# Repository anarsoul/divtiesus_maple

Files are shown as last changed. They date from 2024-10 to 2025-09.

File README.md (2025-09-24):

# [DivTIESUS Maple Edition](https://anarsoul.github.io/divtiesus_maple)
DivTIESUS Maple Edition is a SD/MMC card interface for the ZX Spectrum. It is based on Miguel's [DivTIESUS](https://github.com/mcleod-ideafix/divtiesus), but adds joystick port and serial port for WiFi at the expense of Soft +3E feature. I redid whole project in KiCAD and rerouted the PCB. CPLD pin assignment has been changed to accommodate new PCB layout.

You can [buy me a coffee](https://ko-fi.com/anarsoul) if you want to say thank you.

# Features
- DivMMC compatible interface with 8 KiB of EEPROM and 128 KiB or 512 KiB of RAM. Standard utils for EEPROM flashing, as provided by the ESXDOS team, are compatible with DivTIESUS.
- Model autodetection. This means you don't need to put a jumper, or flip a switch to change from using it with a Spectrum 48K and a +3.
- Tested with original Spectrum+, Black +2, Harlequin 128 rev. 2D and rev. 4B, Karabas 128 rev. B1. More testing reports will be appreciated
- It uses its own fast clock (24 MHz). It does not need the CPU clock at all.
- NMI button to call file browser in ESXDOS, and handy RESET button.
- MicroSD card slot
- DIP switches for enabling EEPROM flashing and disabling auto-mapping (bottom switch) and for disabling built-in joystick interface (top switch)
- Optional: Zx-Uno-compatible UART (running at 115200 baud) with WiFi. Do not place ESP12 if you are not planning to use it
- Optional: Built-in Kempston joystick interface, compatible with either Atari-style joystick or Sega Genesis joystick (3 or 6-button). Do not place DB9 connector and U6 (74HC165) if you are not planning to use it and disable it with a DIP switch. All 3 buttons are implemented (so called "extended Kempston")
- Joystick interface maps "A" button as "UP" if "Start" button is pressed during machine reset.
- Visual feedback for SD activity (blue led)
- ESXDOS shadowing does not collide with all-RAM feature in +2A/B/3 machines. If the system is in all-RAM mode, ESXDOS ROM mapping is disabled.
- Included STLs for 3D printing an enclosure

# Pictures
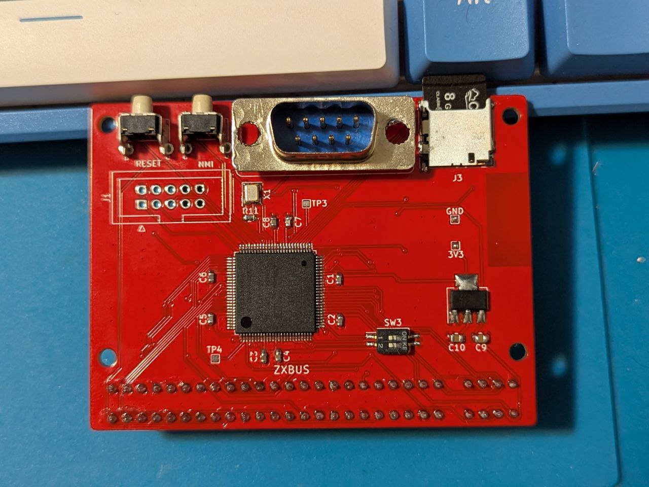
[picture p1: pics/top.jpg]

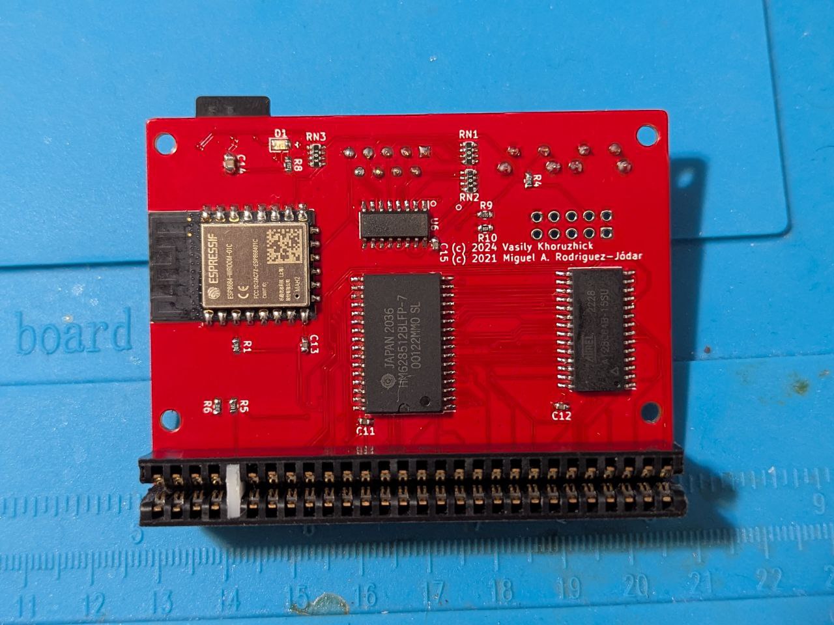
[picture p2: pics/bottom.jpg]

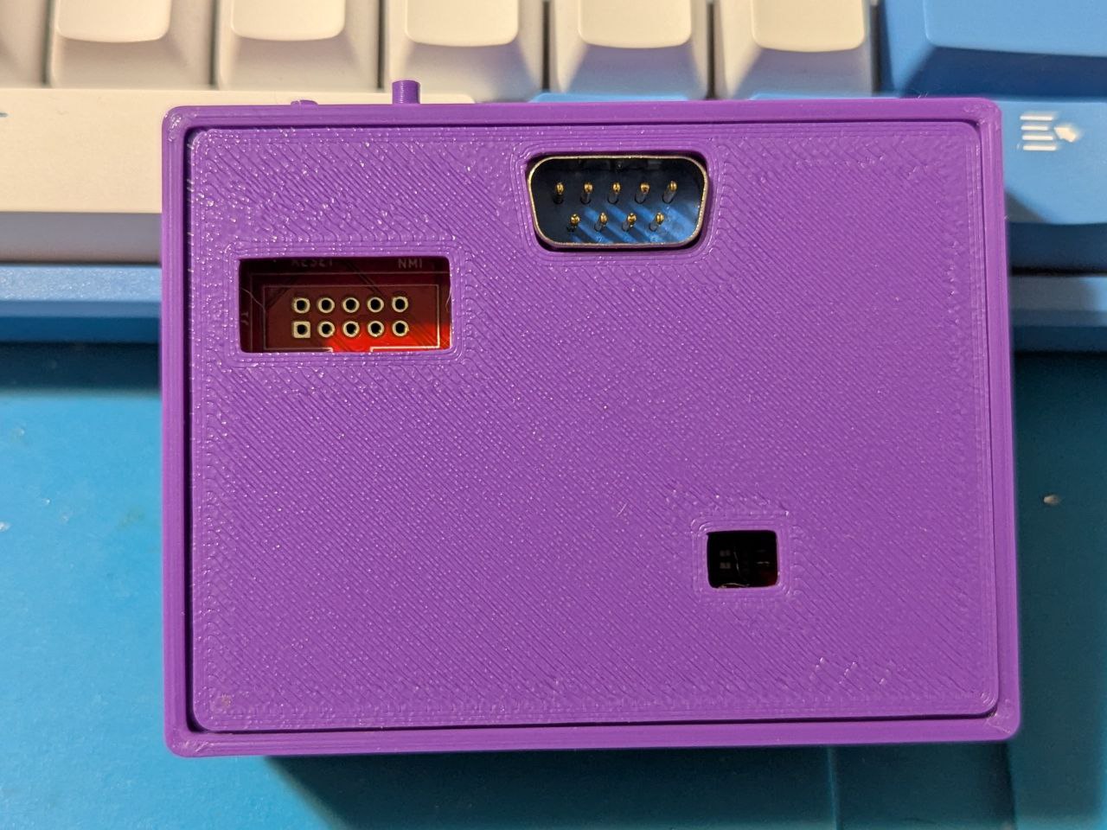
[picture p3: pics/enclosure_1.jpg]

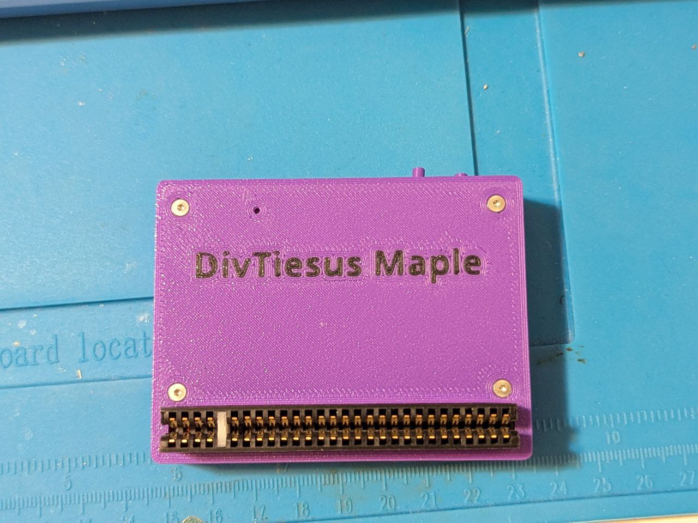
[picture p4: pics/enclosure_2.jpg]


# Schematic

Schematics can be found [here](out/schematics.pdf)

# Build
- First, you need the DivTIESUS Maple Edition PCB. You can order it from JLCPCB or from PCBWay using `divtiesus_maple_rev2.zip` file from out directory. There is also a [project on PCBWay](https://www.pcbway.com/project/shareproject/DivTIESUS_Maple_Edition_rev_2_c9d0d700.html) if you want to support me
- Second, source the components. Most of the components are rather standard so you can buy it off DigiKey or Mouser. All of them can also be obtained from AliExpress. Be careful with components from Aliexpress, especially if the price is too good to be true

## Bill of materials

Interactive BOM can be found [here](out/bom/ibom.html)

Links to some components:

|Qty|Component|Link|
|---|---|---|
|1|EPM240T100|[link](https://www.aliexpress.com/item/1005003990429762.html)|
|1|DIP switches, 2 position|[link](https://www.aliexpress.com/item/33027764033.html)|
|1|RAM|[link](https://www.aliexpress.com/item/1005002495799688.html)|
|1|EEPROM|[link](https://www.aliexpress.com/item/1005003773070206.html)|
|1|ZX Bus connector, 56pin|[link](https://www.aliexpress.com/item/1005002212044956.html)|
|2|Buttons, 6x6x6H|[link](https://www.aliexpress.com/item/1005005129319965.html)|
|1|microSD slot|[link](https://www.aliexpress.com/item/1005006255074403.html)|
|1|Crystal oscillator, 24Mhz|[link](https://www.aliexpress.com/item/1005005879624979.html)|

- The oscillator does not need to be 24 MHz, but if you use a different value, you'll have to resynthesize CPLD image, otherwise WiFi will not work
- I usually start with placing the CPLD first and programming it. Note: you'll need to supply 3.3V in order to program CPLD, there are GND and 3.3V test points left for this purpose. I source CPLDs from Aliexpress and some of them are coming dead. It is easier to test and replace it before the rest of the components are populated.
- Then place the passives (resistors, resistor arrays, capacitors) and the LED
- Then RAM, EEPROM, microSD socket, DB9 connector and ESP12. You can either leave EEPROM blank or preprogram it. Either way is fine, it can be programmed in-system later, but having EEPROM with known contents may simplify troubleshooting

## First electrical testing
- Check that there is no shorts on the 5V and 3.3V power rails.
- Use a microscope or a magnifying glass to check that there is no shorts between adjacent pads at the CPLD chip.

After all the checks, proceed to build and solder the ZX Spectrum bus connector:

## ZX Spectrum bus connector
- Take the 2x28 pin edge connector and cut about 1-2mm on each side to leave the ends opened, refer to original DivTIESUS README.
- Pull and extract the two metal contacts that are positioned at 5th place, where the index tab will be placed
- Now take a small piece you can get from a PCB, 1.5mm thick and 7mm tall. This will be the index tab.
- As an alternative, you can 3D-print the tab, you can find the model [here](https://www.thingiverse.com/thing:6556638)
- Place the tab in the index hole. Sand it if it's too tall for the hole.
- Using a pair of pliers, push it in place. If it's too small for the hole, use some glue to keep it from coming loose.

Now the edge connector is ready to work as a ZX Spectrum rear bus connector!

## Enclosure

Enclosure can be printed in pretty much any plastic. You need `button-2-nmi.stl`, `button-2-reset.stl`, `enclosure.stl` and `enclosure_top.stl` or `enclosure_top_no_jtag_no_switch.stl` if you don't want the holes for JTAG and the switch. Personally, I printed the parts in PLA and PETG. ABS should work as well. Keep in mind that PLA will soften at ~60C, so avoid using it for enclosure if you are planning to use the device with an original machine. Modern clones are fine, they are usually using CMOS ICs and modern voltage regulators that do not produce much heat.

First, place the buttons, short button (reset) closer to the edge

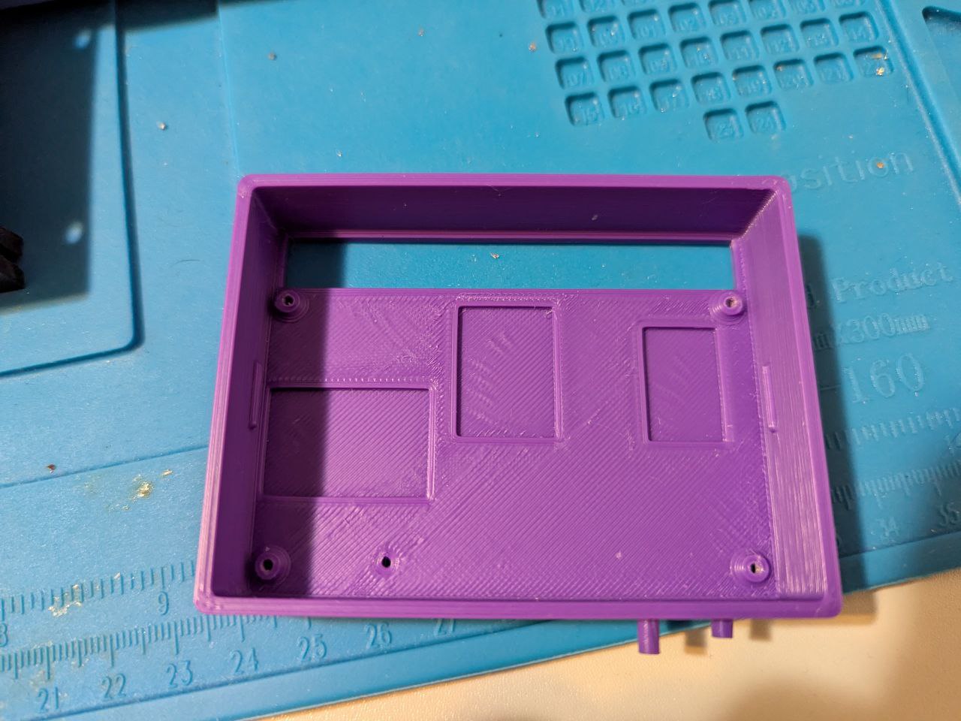
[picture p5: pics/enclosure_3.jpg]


Then insert the PCB. Be careful to keep it straight and don't let the buttons to fall out

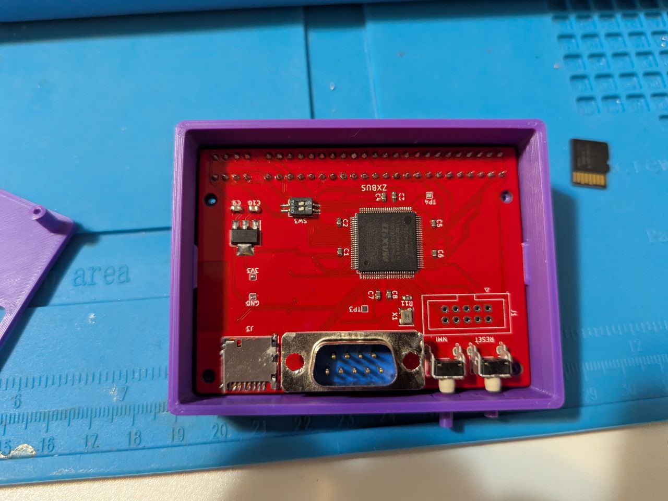
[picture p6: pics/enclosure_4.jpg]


Use 4 M2x8 screws to fix enclosure top

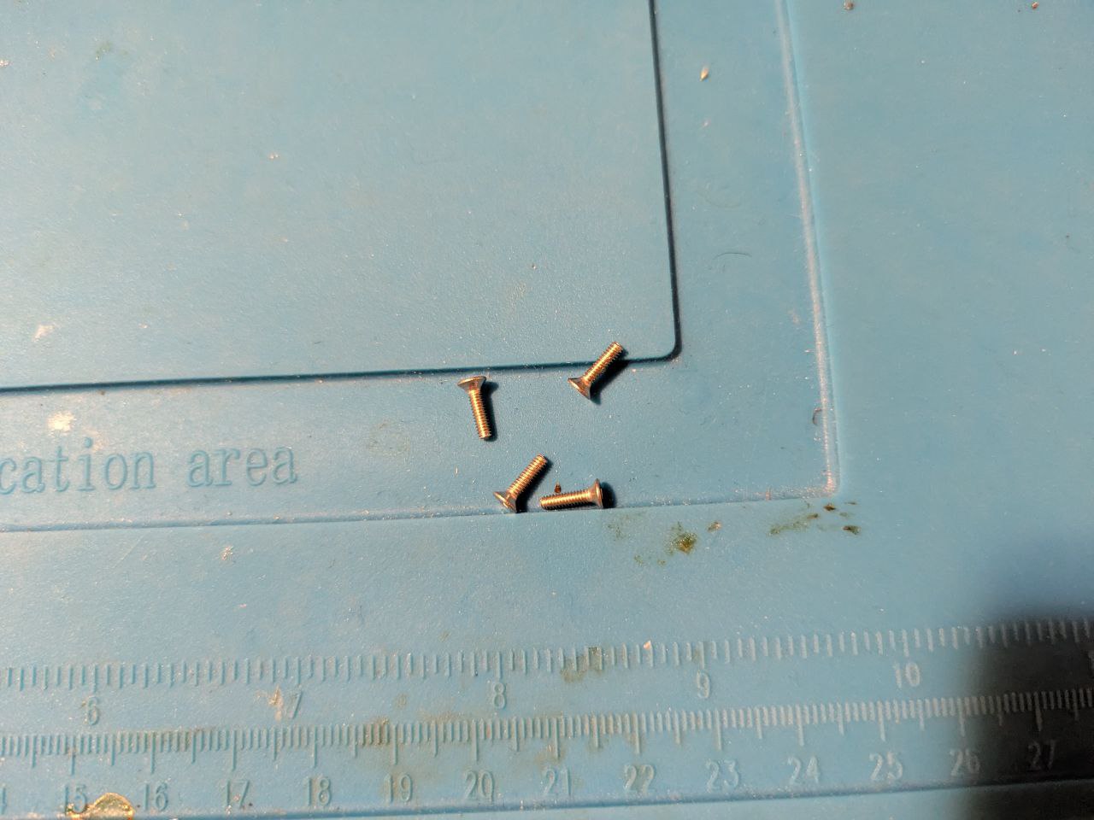
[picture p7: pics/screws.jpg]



## WiFi

DivTiesus Maple Edition implements Zx-Uno-compatible UART, so software compiled for Zx-Uno should work with it.

I recommend using Nihirash's software, [Netman](https://github.com/nihirash/netman-zx) and [Moon Rabbit](https://github.com/nihirash/moon-rabbit-zx). The binaries can be found [here](tools/wifi/zxwifi.zip) - just unpack them onto your SD card and run `netman/NETMAN.BAS` to configure WiFi. WiFi configuration is persistent, so it needs to be done once. Once WiFi is configured you can run `moon_rabbit/MOONR.BAS` to browse gopher sites.

You can also check out my tool for transferring files from PC to Spectrum: [zxmit](https://github.com/anarsoul/zxmit)

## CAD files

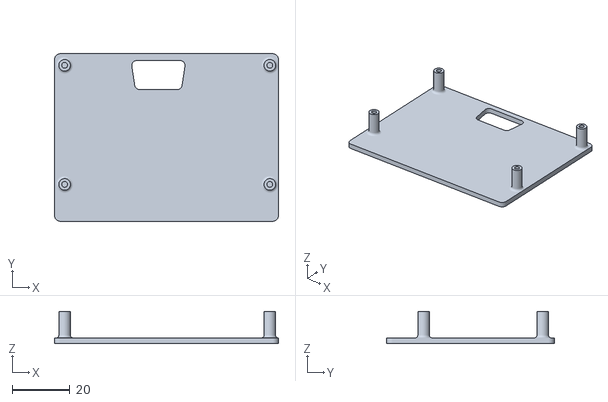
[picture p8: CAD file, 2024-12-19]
out/enclosure/enclosure_top_no_jtag_no_switch.stl
77.4 x 57.9 x 11.2

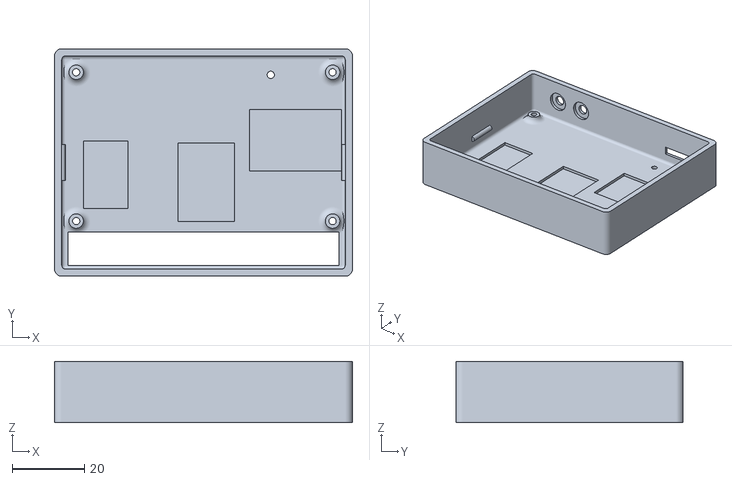
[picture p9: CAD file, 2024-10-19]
out/enclosure/enclosure.stl
82.4 x 62.9 x 17.0

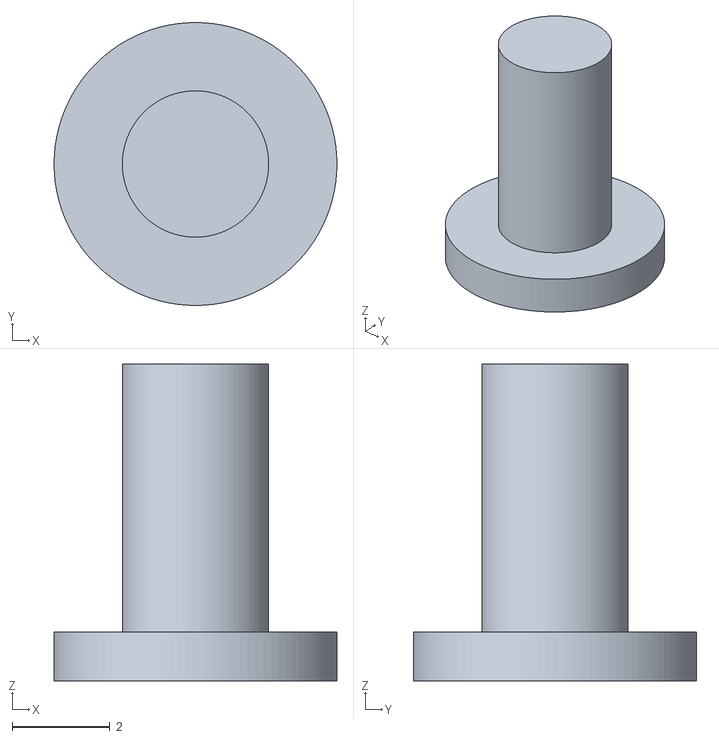
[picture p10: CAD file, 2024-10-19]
out/enclosure/button-2-nmi.stl
5.80 x 5.80 x 6.50

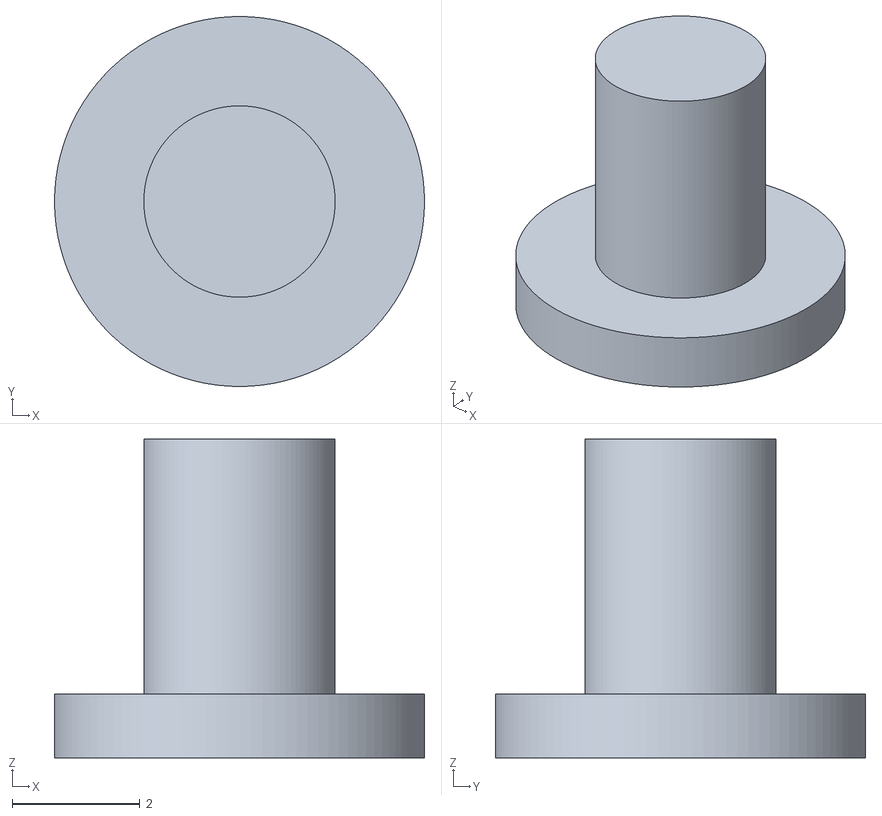
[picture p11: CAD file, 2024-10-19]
out/enclosure/button-2-reset.stl
5.80 x 5.80 x 5.00

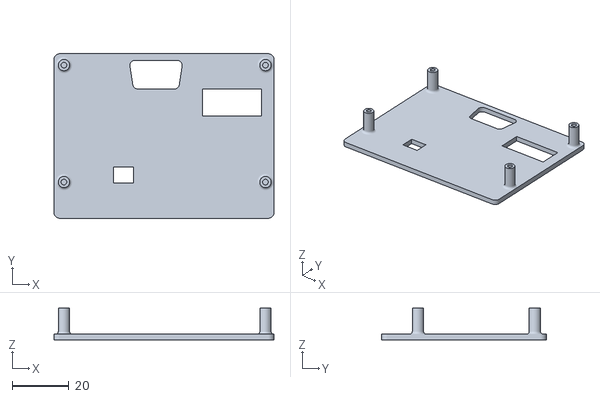
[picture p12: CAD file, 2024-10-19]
out/enclosure/enclosure_top.stl
77.4 x 57.9 x 11.2

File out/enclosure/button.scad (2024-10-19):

$fn = 100;
enclosure_hole_r = 3.4 / 2;
outer_button_r = enclosure_hole_r - 0.2;
inner_button_r = enclosure_hole_r + 1.2;
inner_h = 0.6;
hole_h = inner_h - 0.6;
outer_h = 2; // 3-4 for NMI, 2 for reset
wall_thickness = 2;

cylinder(h = inner_h, r = inner_button_r);
translate([0, 0, inner_h - 0.001]) cylinder(h = outer_h + wall_thickness, r = outer_button_r);

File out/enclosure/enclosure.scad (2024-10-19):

$fn=100;

pcb_width = 76.4;
pcb_height = 56.9;
pcb_wall_gap = 1;
wall_thickness = 2;
enclosure_height = 17;
stand_inner_r = 1;
stand_outer_r = 2;
stand_height = 2;
hole_chamfer_r = 2.5;
connector_hole_height = 9.25;
connector_hole_width = 75;

// top left - [-3mm, -3.5mm]
// top right - [-2.5mm, -3.5mm]
// bottom left - [-3mm , -12.25mm]
// bottom right - [-2.5mm, -12.25mm]
holes = [
            // top left
            [-pcb_width / 2 + 3, pcb_height / 2 - 3.5],
            // top right
            [pcb_width / 2 - 2.5, pcb_height / 2 - 3.5],
            // bottom left
            [-pcb_width / 2 + 3, -pcb_height / 2 + 12.25],
            // bottom right
            [pcb_width / 2 - 2.5, -pcb_height / 2 + 12.25]
];

// ESP dimensions [25.5, 17]
// position [pcb_width / 2, pcb_height / 2 - 13.8]
esp_width = 25.5;
esp_height = 17;
esp_x = pcb_width / 2 - esp_width / 2;
esp_y = pcb_height / 2 - 13.8 - esp_height / 2;

// RAM 628128 (628512) dimensions [15.6, 21.7]
// position [pcb_width / 2 - 29,6, pcb_height / 2 - 23]
ram_width = 15.6;
ram_height = 21.7;
ram_x = pcb_width / 2 - 29.6 - ram_width / 2;
ram_y = pcb_height / 2 - 23 - ram_height / 2;

// ROM 28C24 dimensions [12.3, 18.7]
// position [-pcb_width / 2 + 5, pcb_height / 2 - 22.5
rom_width = 12.3;
rom_height = 18.7;
rom_x = -pcb_width / 2 + 5 + rom_width / 2;
rom_y = pcb_height / 2 - 22.5 - rom_height / 2;

// reset and nmi,
// height from stand to center = 5.5
// reset x = pcb_width / 2 - 10.1
// nmi x = pcb_width / 2 - 20.3
button_r = 3.4 / 2;
button_y = pcb_height / 2;
nmi_x = -pcb_width / 2 + 20.3;
reset_x = -pcb_width / 2 + 10.1;
button_z = -enclosure_height / 2 + wall_thickness + stand_height + 5.5;

// microSD
// height from stand to center = 2.8
// x = pcb_width / 2 - 5
microsd_height = 2.8;
microsd_width = 13.85;
microsd_x = pcb_width / 2 - 5 - microsd_width / 2;
microsd_y = pcb_height / 2;
microsd_z = -enclosure_height / 2 + wall_thickness + stand_height + 2.8;

module rounded_rect(x, y, z, r)
{
    linear_extrude(z, center = true) minkowski() {
        square([x, y], center = true);
        circle(r = r);
    }
}

module stand(outer_r, inner_r, h) {
    difference() {
        cylinder(h = h, r = outer_r, center = true);
        cylinder(h = h + 0.002, r = inner_r, center = true); 
    }
    difference() {
        rotate_extrude() translate([outer_r + h / 2 - 0.001, 0]) square([h, h], center = true);
        rotate_extrude() translate([outer_r + h, h / 2]) circle(r = h);
    }
}

difference() {

    union() {
        difference() {
            // base
            rounded_rect(pcb_width + pcb_wall_gap * 2, pcb_height + pcb_wall_gap * 2, enclosure_height, wall_thickness);
            // cut out
            translate([0, 0, wall_thickness])
                minkowski() {
                    cube([pcb_width + pcb_wall_gap * 2 - wall_thickness, pcb_height + pcb_wall_gap * 2 - wall_thickness, enclosure_height - wall_thickness], center = true);
                    sphere(r = wall_thickness / 2);
                }
            // holes
            for (idx = [ 0 : len(holes) - 1 ]) {
                translate(holes[idx]) {
                    cylinder(h = enclosure_height * 2, r = stand_inner_r, center = true);
                    // chamfer
                    translate([0, 0, (-enclosure_height / 2 - 0.001 + hole_chamfer_r / 2)]) cylinder(h = hole_chamfer_r, r1 = hole_chamfer_r, r2 = 0, center = true);
                }
            }
        }

        // PCB stands
        for (idx = [ 0 : len(holes) - 1 ])
            translate(holes[idx])
                translate([0, 0, -enclosure_height / 2 + stand_height / 2 + wall_thickness + 0.001])
                    stand(stand_outer_r, stand_inner_r, stand_height);
        
        // PCB locks
        translate([pcb_width / 2 + pcb_wall_gap, 0, -enclosure_height / 2 + wall_thickness + stand_height + 1.8 + 0.5]) rotate([90, 0, 0]) cylinder(h = 10, r = 1, center = true);
        translate([-pcb_width / 2 - pcb_wall_gap, 0, -enclosure_height / 2 + wall_thickness + stand_height + 1.8 + 0.5]) rotate([90, 0, 0]) cylinder(h = 10, r = 1, center = true);
    }
    // connector hole
    translate([0, -pcb_height / 2 - wall_thickness - pcb_wall_gap + 3 + connector_hole_height / 2]) 
        cube([connector_hole_width, connector_hole_height, enclosure_height * 2], center = true);
    
    // ESP
    translate([esp_x, esp_y, -enclosure_height / 2 + wall_thickness + 0.001]) cube([esp_width, esp_height, 2], center = true);
    
    // RAM
    translate([ram_x, ram_y, -enclosure_height / 2 + wall_thickness + 0.001]) cube([ram_width, ram_height, 2], center = true);
    
    // ROM
    translate([rom_x, rom_y, -enclosure_height / 2 + wall_thickness + 0.001]) cube([rom_width, rom_height, 2], center = true);
    
    // NMI
    translate([nmi_x, button_y, button_z]) rotate([90, 0, 0]) cylinder(h = 10, r = button_r, center = true);
    translate([nmi_x, button_y, button_z]) rotate([90, 0, 0]) cylinder(h=4, r = button_r + 1.6, center = true);
        
    // Reset
    translate([reset_x, button_y, button_z]) rotate([90, 0, 0]) cylinder(h = 10, r = button_r, center = true);
    translate([reset_x, button_y, button_z]) rotate([90, 0, 0]) cylinder(h=4, r = button_r + 1.6, center = true);
    
    // MicroSD
    translate([microsd_x, microsd_y, microsd_z]) cube([microsd_width, 10, microsd_height], center = true);
    translate([microsd_x, microsd_y + 4, microsd_z]) cube([microsd_width + 2, 4, microsd_height + 2], center = true);
    
    // LED
    translate([pcb_width / 2 - 19.6, pcb_height / 2 - 4.2]) cylinder(h = enclosure_height * 2, r = 1, center = true);

}

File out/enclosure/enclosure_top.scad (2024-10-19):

$fn = 100;

pcb_width = 76.4;
pcb_height = 56.9;
pcb_wall_gap = 1;
wall_thickness = 2;
enclosure_height = 17;
stand_inner_r = 1;
stand_outer_r = 2;
stand_height = 2;
hole_chamfer_r = 2;
connector_hole_height = 9.25;
connector_hole_width = 75;
pcb_thickness = 1.6;
tolerance = 0.2;

top_stand_height = enclosure_height - wall_thickness * 2 - stand_height - 1.6 - tolerance;

holes = [
            // top left
            [-pcb_width / 2 + 3, pcb_height / 2 - 3.5],
            // top right
            [pcb_width / 2 - 2.5, pcb_height / 2 - 3.5],
            // bottom left
            [-pcb_width / 2 + 3, -pcb_height / 2 + 12.25],
            // bottom right
            [pcb_width / 2 - 2.5, -pcb_height / 2 + 12.25]
];

jtag_width = 20.7;
jtag_height = 9.45;
jtag_x = pcb_width / 2 - 3.9 - jtag_width / 2;
jtag_y = pcb_height / 2 - 12 - jtag_height / 2;

switch_width = 5.95;
switch_height = 4.45;
switch_x = -pcb_width / 2 + 21 + switch_width / 2;
switch_y = -pcb_height / 2 + 12.55 + switch_height / 2;

module rounded_rect(x, y, z, r)
{
    linear_extrude(z, center = true) minkowski() {
        square([x, y], center = true);
        circle(r = r);
    }
}

module stand(outer_r, inner_r, h, fillet_h) {
    difference() {
        cylinder(h = h, r = outer_r, center = true);
        cylinder(h = h + 0.002, r = inner_r, center = true); 
    }
    translate([0, 0, -h / 2 + fillet_h / 2]) difference() {
        rotate_extrude() translate([outer_r + fillet_h / 2 - 0.001, 0]) square([fillet_h, fillet_h], center = true);
        rotate_extrude() translate([outer_r + fillet_h, fillet_h / 2]) circle(r = fillet_h);
    }
}

difference() {
    union() {
        rounded_rect(pcb_width - wall_thickness * 2 + 1, pcb_height - wall_thickness * 2 + 1, wall_thickness, wall_thickness);

        for (idx = [ 0 : len(holes) - 1 ])
                    translate(holes[idx])
                        translate([0, 0, wall_thickness / 2 + top_stand_height / 2 - 0.001])
                            stand(stand_outer_r, stand_inner_r, top_stand_height, 1);
    }
    
    translate([jtag_x, jtag_y]) cube([jtag_width, jtag_height, 10], center = true);
    translate([switch_x, switch_y]) cube([switch_width + 1.2, switch_height + 1.2, 10], center = true);
    
    joystick_r = 1.75;
    joystick_h = 8.65 + tolerance * 7;
    joystick_w1 = 17 + tolerance * 7;
    joystick_w2 = 15 + tolerance * 7;
    joystick_x = -(pcb_width / 2 - 27.2 + 1 - joystick_w1 / 2);
    joystick_y = pcb_height / 2 - 2.35 + 0.5 - joystick_h / 2;
    
    translate([joystick_x, joystick_y]) linear_extrude(10, center = true) hull() {
        translate([-joystick_w1 / 2 + joystick_r, joystick_h / 2 - joystick_r]) circle(r = joystick_r);
        translate([joystick_w1 /2 - joystick_r, joystick_h / 2 - joystick_r]) circle(r = joystick_r);
        translate([-joystick_w2 / 2 + joystick_r, -joystick_h / 2 + joystick_r]) circle(r = joystick_r);
        translate([joystick_w2 / 2 - joystick_r, -joystick_h / 2 + joystick_r]) circle(r = joystick_r);
    }
}

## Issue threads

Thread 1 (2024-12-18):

New assembled board doesn't boot

serperus, 2024-12-18:
Hi,

Fresh new board, cpld was programmed with generated .pof by using tld_divtiesus.qpf project.
If I disable interface by the switch - ZX boots ok, If the jumper is open - no boot.
I use Harlequin 128k (issue 2d). The original zx spectrum 48k - the same.
SD light is constantly off.

Thanks for your help

anarsoul, 2024-12-18:
Haha, you are probably the first person beside me who built it :)

Anyway for troubleshooting:

1) Check your soldering with a microscope, especially for EPM240. Try wiggling every pin, it anything moves - reflow it.

2) Did you program the ROM? You can either do it with a standalone programmer, or just set the jumper and load ESXMMC.TAP using tape input. It will program the ROM.

3) If it still doesn't work, you can try loading divramka from [1] to test the RAM.

[1] https://velesoft.speccy.cz/zx/divide/divide-soft.htm

serperus, 2024-12-18:
:)
1) EPM240 tested carefully - all ok
2) ROM was programmed before soldering with esxmmc.bin - ok
3) Loaded Divramka - it blinks different border colors, then write some black pixels at the top of the screen and resets the spectrum. No human readable output )

anarsoul, 2024-12-18:
Sounds like some of the EPM pins aren't making contact with the connector, so it drives the data bus when it's not supposed to. Check again for shorts and then check connectivity between the connector and the EPM

serperus, 2024-12-18:
Maybe the .pof file is the problem? Do I use the right way to generate it? If I use .pof from cpld github directory - zx even doensn't boot while disable jumper is shorted.
Can you please provide me with the correct firmware for it?

anarsoul, 2024-12-18:
I believe that the POF is fine. Can you show high res pictures of the PCB, both top and bottom sides?

serperus, 2024-12-18:
Ok, will do it tomorrow.
I didn't solder the esp module. I didn't think it was important to start

anarsoul, 2024-12-18:
Yeah, it will work fine without ESP and/or shift register

anarsoul, 2024-12-18:
I recompiled the POF and moved it to out directory. I verified that it works fine on my board

serperus, 2024-12-20:
Hi,

The problem was resolved by replacing AT28C64 chip with the new one.
Thanks!

Closed 2025-01-06.

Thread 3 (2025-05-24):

Not work with Sizif-512 and Harlequin Timex 2048

Freiwind, 2025-05-24:
With Harlequin 128 revision 4B it works fine.
Tried connecting to Sizif-512 and Harlequin Timex 2048.
The system does not start. The display shows colored squares (Sizif) or vertical stripes (Timex).
It seems that it incorrectly identifies the models and, accordingly, incorrectly disables the ROM in them.

Freiwind, 2025-05-24:
The issue with Sizif is resolved. Indeed, there were no 9 volts on the B4 bus contact.
Connected 5 volts to this contact. This is enough for EPM240 after the divider.

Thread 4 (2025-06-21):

Update the silk screen

oO-cozy-Oo, 2025-06-21:
Hi Anarsoul,
                  Great job on this pcb but could i ask if you could update the silk screen on the cpld as there is two circles on the CPLD a smal circle and a larger one, I did think the larger one being the main one and soldered it in the wrong postion it took me age.... if the silk shown both it would stop this.

Cheers Cozy

Closed 2025-06-25.

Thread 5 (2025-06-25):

BOM ?

oO-cozy-Oo, 2025-06-25:
Hi Anarsoul,
                 Just a newbie question on the BOM=    R9, R11     510         R_0603_1608Metric,
Is this 510R  or 510K.

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

cheers Cozy

anarsoul, 2025-06-25:
It is a common convention, 510 stands for 510 Ohm.

Closed 2025-06-25.

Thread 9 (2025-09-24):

divtiesus_maple WIFI

sadovsky-dmitry, 2025-09-24:
Vasily Khoruzhick добрый вечер. Спасибо за divtiesus_maple суппер штука! Вот пытаюсь настроить wifi и выйти в интернет через zx Spectrum 128 Toastrack. Хотелось бы инструкцию по настройки wifi и выход в интернет). Сейчас закинул в папку 3 файла font.bin , NETMAN.BAS, netman.cod…

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

sadovsky-dmitry, 2025-09-24:
Так запустил NETMAN.BAS нашел свою сеть и ввел пароль написало что произошел коннект все ок. А теперь как попасть на архив zx spectrum ))) и как скачивать можно ?)

anarsoul, 2025-09-24:
Готово: https://anarsoul.github.io/divtiesus_maple/#wifi

Closed 2025-09-24.

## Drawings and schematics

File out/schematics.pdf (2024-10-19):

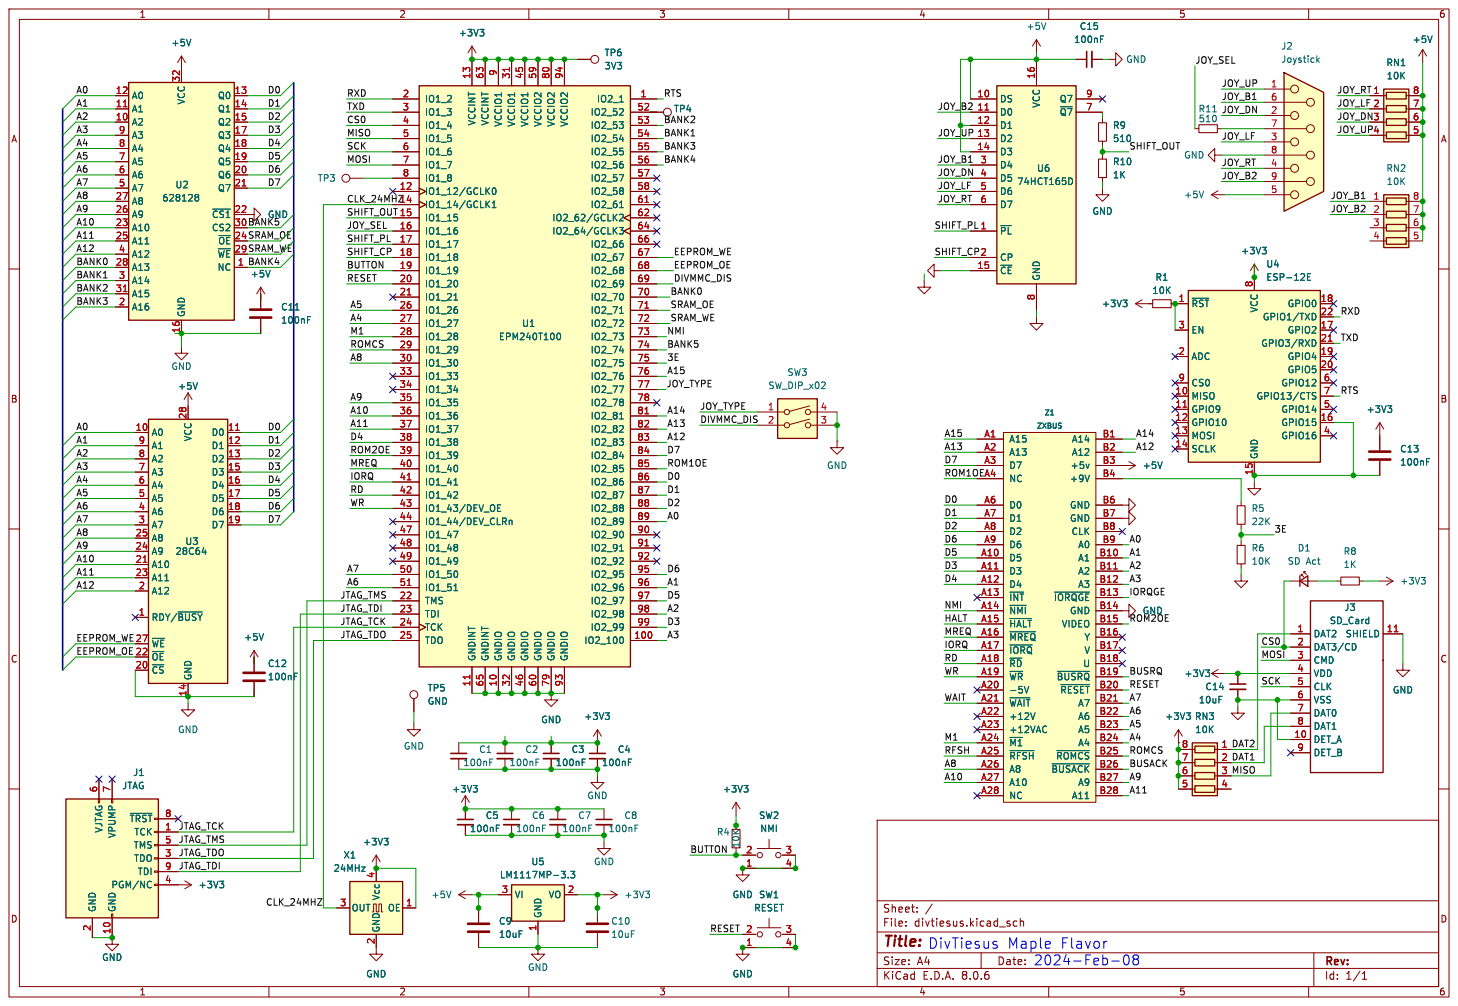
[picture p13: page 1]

2 TDO 3 PGM/NC 4 TMS 5 VJTAG

Id: 1/1 Title: File: divtiesus.kicad_sch Sheet: /

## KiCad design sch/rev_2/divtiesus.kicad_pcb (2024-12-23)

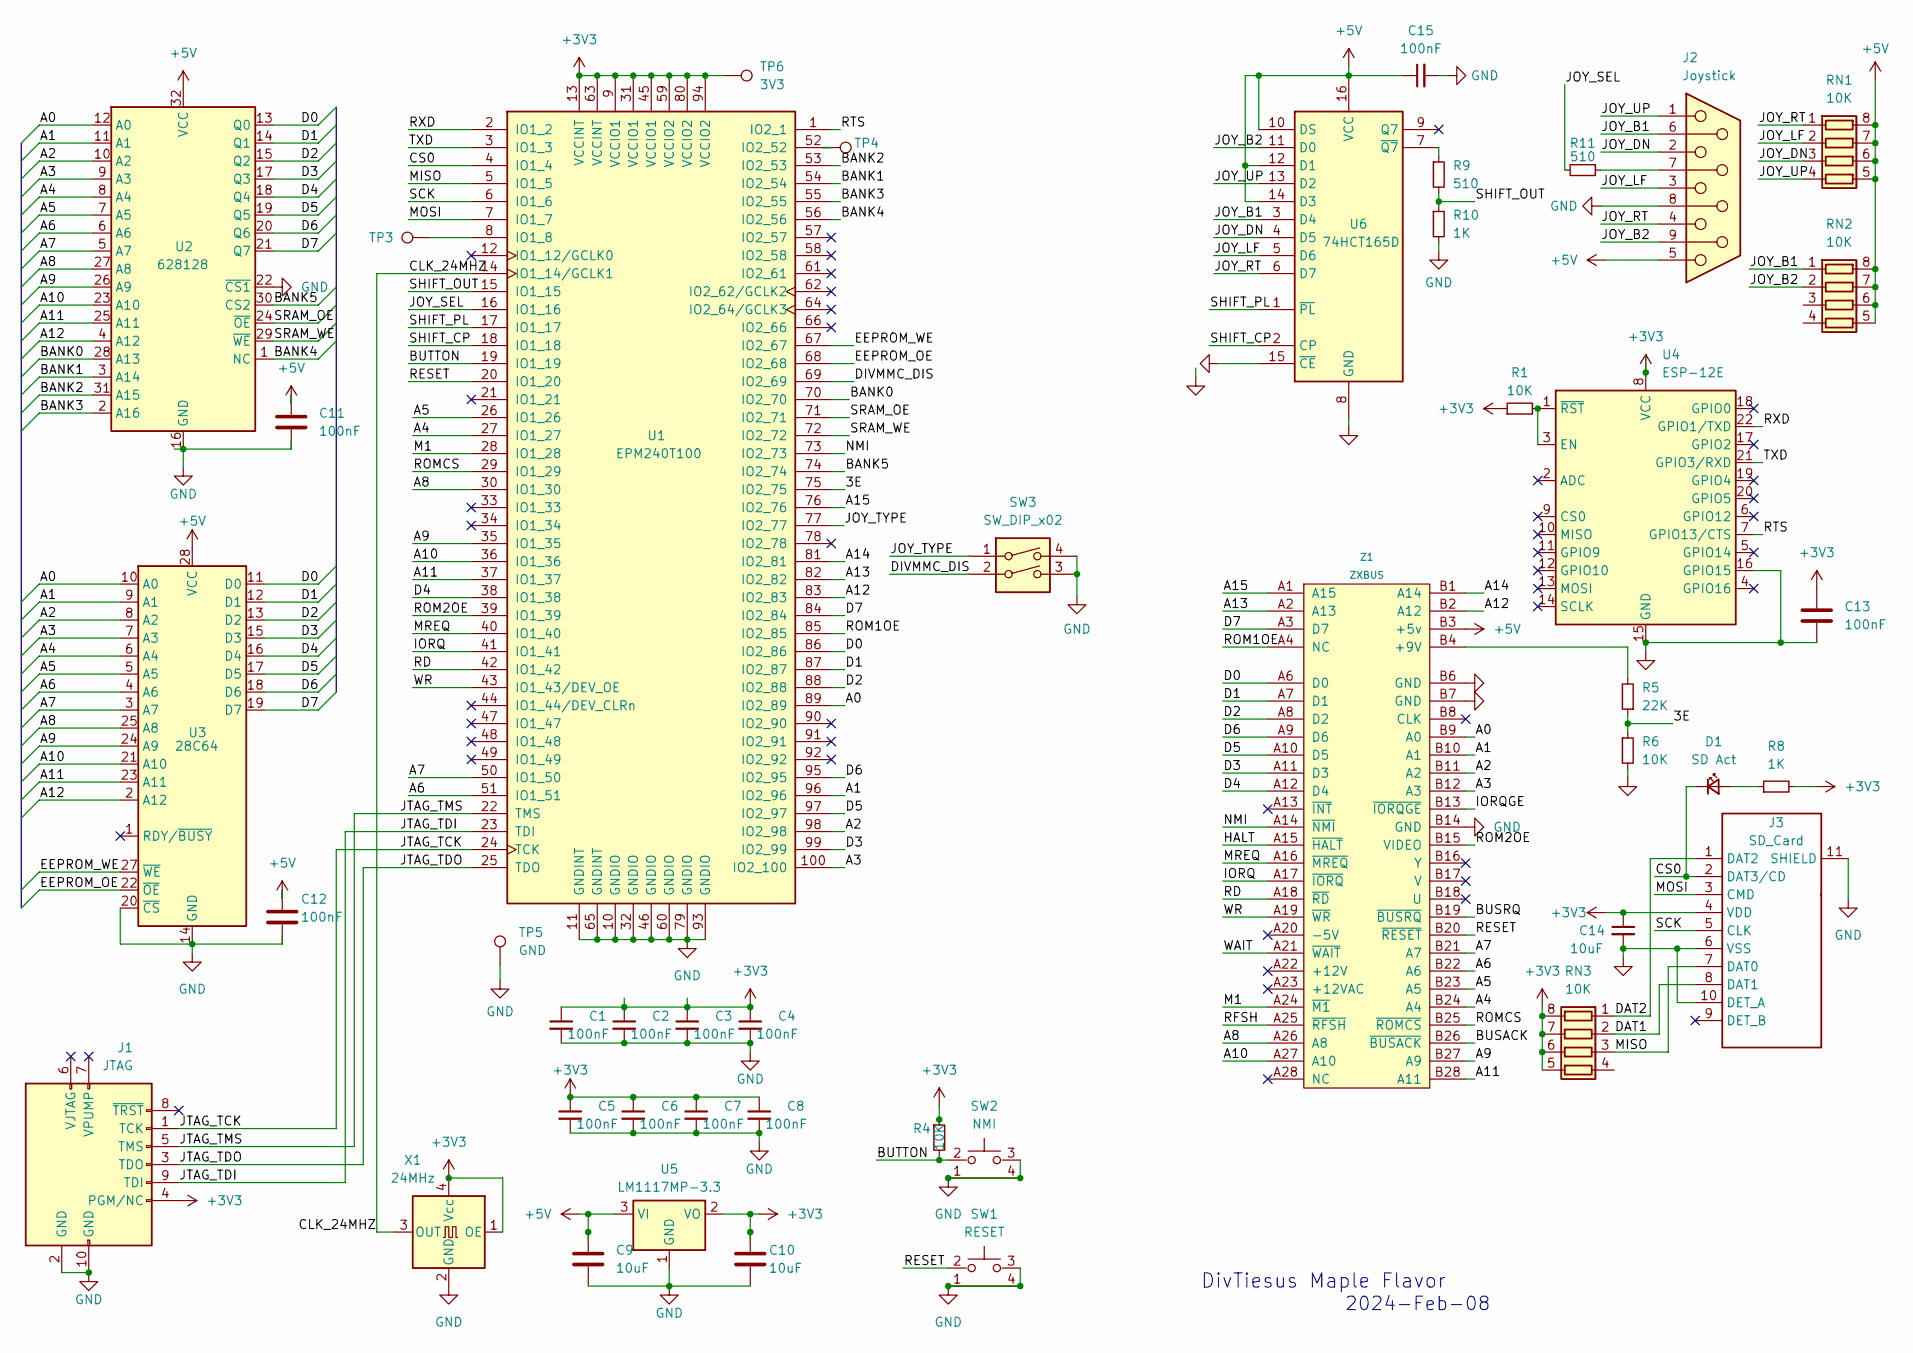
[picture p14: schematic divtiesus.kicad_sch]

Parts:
C1, C2, C3, C4, C5, C6, C7, C8, C11, C12, C13, C15: 100nF; C_0603_1608Metric
C9, C10, C14: 10uF; C_0805_2012Metric
D1: SD Act; LED_0805_2012Metric
J1: JTAG; IDC-Header_2x05_P2.54mm_Vertical
J2: Joystick; DSUB-9_Male_Vertical_P2.77x2.84mm
J3: SD_Card; microSD_HC_Hirose_DM3D-SF; PARTREV AX6
R1, R4, R6: 10K; R_0603_1608Metric
R5: 22K; R_0603_1608Metric
R8, R10: 1K; R_0603_1608Metric
R9, R11: 510; R_0603_1608Metric
RN1, RN2, RN3: 10K; R_Array_Convex_4x0603
SW1: RESET; SW_Tactile_SPST_Angled_PTS645Vx58-2LFS
SW2: NMI; SW_Tactile_SPST_Angled_PTS645Vx58-2LFS
SW3: SW_DIP_x02; SW_DIP_SPSTx02_Slide_Copal_CHS-02B_W7.62mm_P1.27mm
TP3, TP4: TestPoint_Pad_1.0x1.0mm
TP5: GND; TestPoint_Pad_1.0x1.0mm
TP6: 3V3; TestPoint_Pad_1.0x1.0mm
U1: EPM240T100; TQFP-100_14x14mm_P0.5mm
U2: 628128; SSOP-32_11.305x20.495mm_P1.27mm
U3: 28C64; SOIC-28W_7.5x17.9mm_P1.27mm
U4: ESP-12E
U5: LM1117MP-3.3; SOT-223-3_TabPin2
U6: 74HCT165D; SOIC-16_3.9x9.9mm_P1.27mm
X1: 24MHz; Oscillator_SMD_SeikoEpson_SG8002CE-4Pin_3.2x2.5mm
Z1: ZXBUS; CONECTOR_SIMPLE_CARA

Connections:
+3V3: C1.1, C2.1, C3.1, C4.1, C5.1, C6.1, C7.1, C8.1, C10.1, C13.1, C14.1, J1.4 (PGM/NC), J3.4 (VDD), R1.1, R4.1, R8.2, RN3.5 (R4.2), RN3.6 (R3.2), RN3.7 (R2.2), RN3.8 (R1.2), TP6.1, U1.9 (VCCIO1), U1.13 (VCCINT), U1.31 (VCCIO1), U1.45 (VCCIO1), U1.59 (VCCIO2), U1.63 (VCCINT), U1.80 (VCCIO2), U1.94 (VCCIO2), U4.8 (VCC), U5.2 (VO), X1.1 (OE), X1.4 (Vcc)
+5V: C9.1, C11.1, C12.1, C15.1, J2.5, RN1.5 (R4.2), RN1.6 (R3.2), RN1.7 (R2.2), RN1.8 (R1.2), RN2.5 (R4.2), RN2.6 (R3.2), RN2.7 (R2.2), RN2.8 (R1.2), U2.32 (VCC), U3.28 (VCC), U5.3 (VI), U6.10 (DS), U6.12 (D1), U6.14 (D3), U6.16 (VCC), Z1.B3 (+5v)
/3E: R5.1, R6.1, U1.75 (IO2_75)
/A0: U1.89 (IO2_89), U2.12 (A0), U3.10 (A0), Z1.B9 (A0)
/A1: U1.96 (IO2_96), U2.11 (A1), U3.9 (A1), Z1.B10 (A1)
/A2: U1.98 (IO2_98), U2.10 (A2), U3.8 (A2), Z1.B11 (A2)
/A3: U1.100 (IO2_100), U2.9 (A3), U3.7 (A3), Z1.B12 (A3)
/A4: U1.27 (IO1_27), U2.8 (A4), U3.6 (A4), Z1.B24 (A4)
/A5: U1.26 (IO1_26), U2.7 (A5), U3.5 (A5), Z1.B23 (A5)
/A6: U1.51 (IO1_51), U2.6 (A6), U3.4 (A6), Z1.B22 (A6)
/A7: U1.50 (IO1_50), U2.5 (A7), U3.3 (A7), Z1.B21 (A7)
/A8: U1.30 (IO1_30), U2.27 (A8), U3.25 (A8), Z1.A26 (A8)
/A9: U1.35 (IO1_35), U2.26 (A9), U3.24 (A9), Z1.B27 (A9)
/A10: U1.36 (IO1_36), U2.23 (A10), U3.21 (A10), Z1.A27 (A10)
/A11: U1.37 (IO1_37), U2.25 (A11), U3.23 (A11), Z1.B28 (A11)
/A12: U1.83 (IO2_83), U2.4 (A12), U3.2 (A12), Z1.B2 (A12)
/A13: U1.82 (IO2_82), Z1.A2 (A13)
/A14: U1.81 (IO2_81), Z1.B1 (A14)
/A15: U1.76 (IO2_76), Z1.A1 (A15)
/BANK0: U1.70 (IO2_70), U2.28 (A13)
/BANK1: U1.54 (IO2_54), U2.3 (A14)
/BANK2: U1.53 (IO2_53), U2.31 (A15)
/BANK3: U1.55 (IO2_55), U2.2 (A16)
/BANK4: U1.56 (IO2_56), U2.1 (NC)
/BANK5: U1.74 (IO2_74), U2.30 (CS2)
/BUSACK: Z1.B26 (~BUSACK)
/BUSRQ: Z1.B19 (~BUSRQ)
/BUTTON: R4.2, SW2.2, U1.19 (IO1_19)
/CLK_24MHZ: U1.14 (IO1_14/GCLK1), X1.3 (OUT)
/CS0: D1.1 (K), J3.2 (DAT3/CD), U1.4 (IO1_4)
/D0: U1.86 (IO2_86), U2.13 (Q0), U3.11 (D0), Z1.A6 (D0)
/D1: U1.87 (IO2_87), U2.14 (Q1), U3.12 (D1), Z1.A7 (D1)
/D2: U1.88 (IO2_88), U2.15 (Q2), U3.13 (D2), Z1.A8 (D2)
/D3: U1.99 (IO2_99), U2.17 (Q3), U3.15 (D3), Z1.A11 (D3)
/D4: U1.38 (IO1_38), U2.18 (Q4), U3.16 (D4), Z1.A12 (D4)
/D5: U1.97 (IO2_97), U2.19 (Q5), U3.17 (D5), Z1.A10 (D5)
/D6: U1.95 (IO2_95), U2.20 (Q6), U3.18 (D6), Z1.A9 (D6)
/D7: U1.84 (IO2_84), U2.21 (Q7), U3.19 (D7), Z1.A3 (D7)
/DAT1: J3.8 (DAT1), RN3.2 (R2.1)
/DAT2: J3.1 (DAT2), RN3.1 (R1.1)
/DIVMMC_DIS: SW3.2, U1.69 (IO2_69)
/EEPROM_OE: U1.68 (IO2_68), U3.22 (~OE)
/EEPROM_WE: U1.67 (IO2_67), U3.27 (~WE)
/HALT: Z1.A15 (~HALT)
/IORQ: U1.41 (IO1_41), Z1.A17 (~IORQ)
/IORQGE: Z1.B13 (~IORQGE)
/JOY_B1: J2.6, RN2.1 (R1.1), U6.3 (D4)
/JOY_B2: J2.9, RN2.2 (R2.1), U6.11 (D0)
/JOY_DN: J2.2, RN1.3 (R3.1), U6.4 (D5)
/JOY_LF: J2.3, RN1.2 (R2.1), U6.5 (D6)
/JOY_RT: J2.4, RN1.1 (R1.1), U6.6 (D7)
/JOY_SEL: R11.2, U1.16 (IO1_16)
/JOY_TYPE: SW3.1, U1.77 (IO2_77)
/JOY_UP: J2.1, RN1.4 (R4.1), U6.13 (D2)
/JTAG_TCK: J1.1 (TCK), U1.24 (TCK)
/JTAG_TDI: J1.9 (TDI), U1.23 (TDI)
/JTAG_TDO: J1.3 (TDO), U1.25 (TDO)
/JTAG_TMS: J1.5 (TMS), U1.22 (TMS)
/M1: U1.28 (IO1_28), Z1.A24 (~M1)
/MISO: J3.7 (DAT0), RN3.3 (R3.1), U1.5 (IO1_5)
/MOSI: J3.3 (CMD), U1.7 (IO1_7)
/MREQ: U1.40 (IO1_40), Z1.A16 (~MREQ)
/NMI: U1.73 (IO2_73), Z1.A14 (~NMI)
/RD: U1.42 (IO1_42), Z1.A18 (~RD)
/RESET: SW1.2, U1.20 (IO1_20), Z1.B20 (~RESET)
/RFSH: Z1.A25 (~RFSH)
/ROM1OE: U1.85 (IO2_85), Z1.A4 (NC)
/ROM2OE: U1.39 (IO1_39), Z1.B15 (VIDEO)
/ROMCS: U1.29 (IO1_29), Z1.B25 (~ROMCS)
/RTS: U1.1 (IO2_1), U4.7 (GPIO13/CTS)
/RXD: U1.2 (IO1_2), U4.22 (GPIO1/TXD)
/SCK: J3.5 (CLK), U1.6 (IO1_6)
/SHIFT_CP: U1.18 (IO1_18), U6.2 (CP)
/SHIFT_OUT: R9.2, R10.1, U1.15 (IO1_15)
/SHIFT_PL: U1.17 (IO1_17), U6.1 (~PL)
/SRAM_OE: U1.71 (IO2_71), U2.24 (~OE)
/SRAM_WE: U1.72 (IO2_72), U2.29 (~WE)
/TXD: U1.3 (IO1_3), U4.21 (GPIO3/RXD)
/WAIT: Z1.A21 (~WAIT)
/WR: U1.43 (IO1_43/DEV_OE), Z1.A19 (~WR)
GND: C1.2, C2.2, C3.2, C4.2, C5.2, C6.2, C7.2, C8.2, C9.2, C10.2, C11.2, C12.2, C13.2, C14.2, C15.2, J1.2 (GND), J1.10 (GND), J2.8, J3.6 (VSS), J3.10 (DET_A), J3.11 (SHIELD), R6.2, R10.2, SW1.1, SW1.3, SW1.4, SW2.1, SW2.3, SW2.4, SW3.3, SW3.4, TP5.1, U1.10 (GNDIO), U1.11 (GNDINT), U1.32 (GNDIO), U1.46 (GNDIO), U1.60 (GNDIO), U1.65 (GNDINT), U1.79 (GNDIO), U1.93 (GNDIO), U2.16 (GND), U2.22 (~CS1), U3.14 (GND), U3.20 (~CS), U4.15 (GND), U4.16 (GPIO15), U5.1 (GND), U6.8 (GND), U6.15 (~CE), X1.2 (GND), Z1.B6 (GND), Z1.B7 (GND), Z1.B14 (GND)
unnamed: D1.2 (A), R8.1
unnamed: J2.7, R11.1
unnamed: TP3.1, U1.8 (IO1_8)
unnamed: TP4.1, U1.52 (IO2_52)
unnamed: R1.2, U4.1 (~RST), U4.3 (EN)
unnamed: R9.1, U6.7 (~Q7)
unnamed: R5.2, Z1.B4 (+9V)

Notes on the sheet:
2024-Feb-08
DivTiesus Maple Flavor

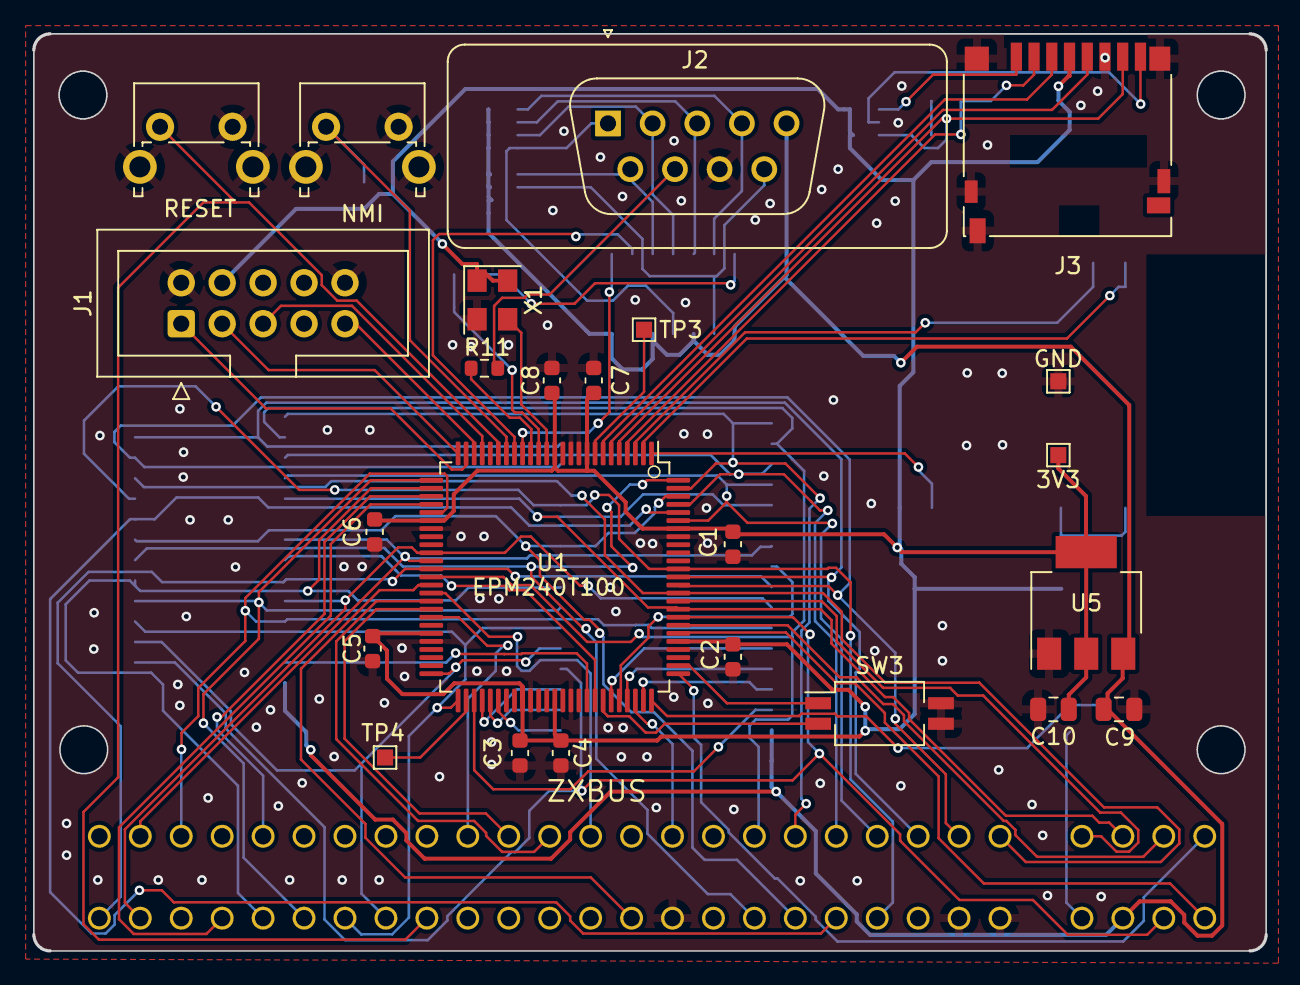
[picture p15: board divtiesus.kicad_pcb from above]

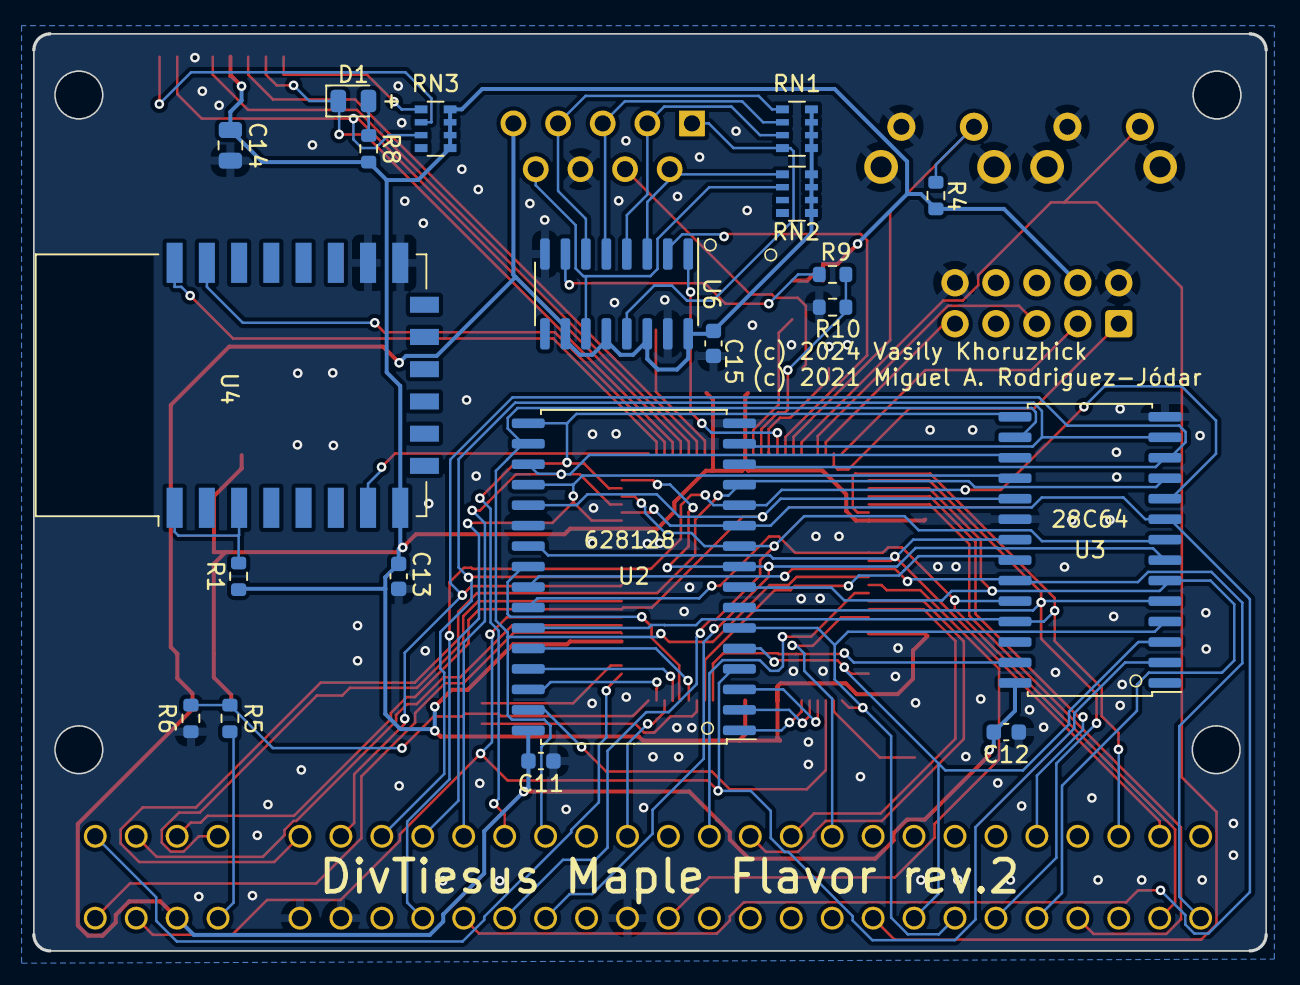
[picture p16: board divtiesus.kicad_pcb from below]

Board: 2 copper layers, 76.5 x 56.9 mm, 45 parts (20 on the bottom side), 82 nets.

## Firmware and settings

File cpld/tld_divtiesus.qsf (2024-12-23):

# -------------------------------------------------------------------------- #
#
# Copyright (C) 2020  Intel Corporation. All rights reserved.
# Your use of Intel Corporation's design tools, logic functions 
# and other software and tools, and any partner logic 
# functions, and any output files from any of the foregoing 
# (including device programming or simulation files), and any 
# associated documentation or information are expressly subject 
# to the terms and conditions of the Intel Program License 
# Subscription Agreement, the Intel Quartus Prime License Agreement,
# the Intel FPGA IP License Agreement, or other applicable license
# agreement, including, without limitation, that your use is for
# the sole purpose of programming logic devices manufactured by
# Intel and sold by Intel or its authorized distributors.  Please
# refer to the applicable agreement for further details, at
# https://fpgasoftware.intel.com/eula.
#
# -------------------------------------------------------------------------- #
#
# Quartus Prime
# Version 20.1.1 Build 720 11/11/2020 SJ Lite Edition
# Date created = 11:33:43  September 21, 2021
#
# -------------------------------------------------------------------------- #
#
# Notes:
#
# 1) The default values for assignments are stored in the file:
#		tld_divtiesus_assignment_defaults.qdf
#    If this file doesn't exist, see file:
#		assignment_defaults.qdf
#
# 2) Altera recommends that you do not modify this file. This
#    file is updated automatically by the Quartus Prime software
#    and any changes you make may be lost or overwritten.
#
# -------------------------------------------------------------------------- #


set_global_assignment -name FAMILY "MAX II"
set_global_assignment -name DEVICE EPM240T100C5
set_global_assignment -name TOP_LEVEL_ENTITY tld_divtiesus
set_global_assignment -name ORIGINAL_QUARTUS_VERSION 20.1.1
set_global_assignment -name PROJECT_CREATION_TIME_DATE "11:33:43  SEPTEMBER 21, 2021"
set_global_assignment -name LAST_QUARTUS_VERSION "23.1std.0 Lite Edition"
set_global_assignment -name PROJECT_OUTPUT_DIRECTORY output_files
set_global_assignment -name MIN_CORE_JUNCTION_TEMP 0
set_global_assignment -name MAX_CORE_JUNCTION_TEMP 85
set_global_assignment -name DEVICE_FILTER_PACKAGE TQFP
set_global_assignment -name DEVICE_FILTER_PIN_COUNT 100
set_global_assignment -name ERROR_CHECK_FREQUENCY_DIVISOR "-1"
set_global_assignment -name POWER_EXT_SUPPLY_VOLTAGE_TO_REGULATOR 3.3V
set_location_assignment PIN_76 -to a[15]
set_location_assignment PIN_81 -to a[14]
set_location_assignment PIN_82 -to a[13]
set_location_assignment PIN_83 -to a[12]
set_location_assignment PIN_37 -to a[11]
set_location_assignment PIN_36 -to a[10]
set_location_assignment PIN_35 -to a[9]
set_location_assignment PIN_30 -to a[8]
set_location_assignment PIN_50 -to a[7]
set_location_assignment PIN_51 -to a[6]
set_location_assignment PIN_26 -to a[5]
set_location_assignment PIN_27 -to a[4]
set_location_assignment PIN_100 -to a[3]
set_location_assignment PIN_98 -to a[2]
set_location_assignment PIN_96 -to a[1]
set_location_assignment PIN_89 -to a[0]
set_location_assignment PIN_14 -to clk25mhz
set_location_assignment PIN_84 -to d[7]
set_location_assignment PIN_95 -to d[6]
set_location_assignment PIN_97 -to d[5]
set_location_assignment PIN_38 -to d[4]
set_location_assignment PIN_99 -to d[3]
set_location_assignment PIN_88 -to d[2]
set_location_assignment PIN_87 -to d[1]
set_location_assignment PIN_86 -to d[0]
set_location_assignment PIN_68 -to eeprom_oe_n
set_location_assignment PIN_67 -to eeprom_we_n
set_location_assignment PIN_41 -to iorq_n
set_location_assignment PIN_69 -to jumper_e
set_location_assignment PIN_28 -to m1_n
set_location_assignment PIN_5 -to miso
set_location_assignment PIN_7 -to mosi
set_location_assignment PIN_40 -to mreq_n
set_location_assignment PIN_19 -to nmi_button_n
set_location_assignment PIN_73 -to nmi_n
set_location_assignment PIN_75 -to notplus3
set_location_assignment PIN_42 -to rd_n
set_location_assignment PIN_85 -to romoe1
set_location_assignment PIN_39 -to romoe2
set_location_assignment PIN_20 -to rst_n
set_location_assignment PIN_6 -to sclk
set_location_assignment PIN_4 -to sd_cs0
set_location_assignment PIN_74 -to sram_hiaddr[5]
set_location_assignment PIN_56 -to sram_hiaddr[4]
set_location_assignment PIN_55 -to sram_hiaddr[3]
set_location_assignment PIN_53 -to sram_hiaddr[2]
set_location_assignment PIN_54 -to sram_hiaddr[1]
set_location_assignment PIN_70 -to sram_hiaddr[0]
set_location_assignment PIN_71 -to sram_oe_n
set_location_assignment PIN_72 -to sram_we_n
set_location_assignment PIN_43 -to wr_n
set_location_assignment PIN_2 -to uart_rx
set_location_assignment PIN_3 -to uart_tx
set_location_assignment PIN_1 -to uart_rts
set_location_assignment PIN_15 -to shift_q
set_location_assignment PIN_18 -to shift_cp
set_location_assignment PIN_17 -to shift_pl
set_location_assignment PIN_16 -to joy_sel
set_global_assignment -name POWER_PRESET_COOLING_SOLUTION "NO HEAT SINK WITH STILL AIR"
set_instance_assignment -name CURRENT_STRENGTH_NEW 8MA -to d[7]
set_instance_assignment -name CURRENT_STRENGTH_NEW 8MA -to d[6]
set_instance_assignment -name CURRENT_STRENGTH_NEW 8MA -to d[5]
set_instance_assignment -name CURRENT_STRENGTH_NEW 8MA -to d[4]
set_instance_assignment -name CURRENT_STRENGTH_NEW 8MA -to d[3]
set_instance_assignment -name CURRENT_STRENGTH_NEW 8MA -to d[2]
set_instance_assignment -name CURRENT_STRENGTH_NEW 8MA -to d[1]
set_instance_assignment -name CURRENT_STRENGTH_NEW 8MA -to d[0]
set_instance_assignment -name CURRENT_STRENGTH_NEW 8MA -to nmi_n
set_global_assignment -name TIMING_ANALYZER_MULTICORNER_ANALYSIS OFF
set_global_assignment -name NUM_PARALLEL_PROCESSORS ALL
set_global_assignment -name AUTO_RESTART_CONFIGURATION OFF
set_global_assignment -name ENABLE_DEVICE_WIDE_RESET OFF
set_global_assignment -name ENABLE_OCT_DONE OFF
set_global_assignment -name ENABLE_CONFIGURATION_PINS OFF
set_global_assignment -name ENABLE_BOOT_SEL_PIN OFF
set_global_assignment -name USE_CONFIGURATION_DEVICE ON
set_global_assignment -name RESERVE_ALL_UNUSED_PINS "AS INPUT TRI-STATED WITH WEAK PULL-UP"
set_global_assignment -name EXTRACT_VERILOG_STATE_MACHINES OFF
set_instance_assignment -name IO_STANDARD "3.3V SCHMITT TRIGGER INPUT" -to a[15]
set_instance_assignment -name IO_STANDARD "3.3V SCHMITT TRIGGER INPUT" -to a[14]
set_instance_assignment -name IO_STANDARD "3.3V SCHMITT TRIGGER INPUT" -to a[13]
set_instance_assignment -name IO_STANDARD "3.3V SCHMITT TRIGGER INPUT" -to a[12]
set_instance_assignment -name IO_STANDARD "3.3V SCHMITT TRIGGER INPUT" -to a[11]
set_instance_assignment -name IO_STANDARD "3.3V SCHMITT TRIGGER INPUT" -to a[10]
set_instance_assignment -name IO_STANDARD "3.3V SCHMITT TRIGGER INPUT" -to a[9]
set_instance_assignment -name IO_STANDARD "3.3V SCHMITT TRIGGER INPUT" -to a[8]
set_instance_assignment -name IO_STANDARD "3.3V SCHMITT TRIGGER INPUT" -to a[7]
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

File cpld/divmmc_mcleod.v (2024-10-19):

/*
 * This file is part of the DivTIESUS project
 * Copyright (c) 2021 Miguel Angel Rodriguez Jodar.
 * 
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
 * You should have received a copy of the GNU General Public License 
 * along with this program. If not, see <http://www.gnu.org/licenses/>.
 */

`timescale 1ns / 1ps
`default_nettype none

module divmmc_mcleod (
  // Interface with CPU
  input wire clk,
  input wire rst_n,
  input wire enable_autopage,  // jumper E = 1 (closed). = 0 (open)  
  input wire [15:0] a,
  input wire [7:0] din,
  input wire mreq_n,
  input wire iorq_n,
  input wire rd_n,
  input wire wr_n,
  input wire m1_n,
  input wire nmi_button_n,  // Button push connects to GND
  output wire nmi_to_cpu_n, // Actual NMI signal to CPU
  // Spectrum ROM shadowing
  input wire inrom48k,
  output wire [7:0] dout,
  output wire [7:0] oe,
  output reg zxromcs,   // 1 to disable ZX ROM.
  // DivMMC onboard memory control
  output reg eeprom_cs,
  output reg eeprom_we_n,
  output reg sram_cs,
  output reg sram_write_n,
  output reg [5:0] sram_hiaddr,  // up to 512KB of SRAM can be addressed
  // SPI interface
  output wire sd_cs0_n,
  //output wire sd_cs1_n,
  output wire sd_sclk,
  output wire sd_mosi,
  input wire sd_miso  
  );

  localparam
    DIVMMC_CTRL = 8'hE3;

  // DIVMMC control register
  reg mapram_mode = 1'b0;
  reg conmem = 1'b0;
  reg [5:0] divmmc_sram_page = 6'b000000;
  wire iorq_wr = iorq_n | wr_n;
  always @(posedge iorq_wr or negedge rst_n) begin
    if (rst_n == 1'b0) begin
      conmem <= 1'b0;
      divmmc_sram_page <= 6'b000000;
    end
    else if (a[7:0]==DIVMMC_CTRL) begin
      conmem <= din[7];
      mapram_mode <= mapram_mode | din[6];
      divmmc_sram_page <= din[5:0];
    end
  end

  // DIVMMC automapper
  reg divmmc_is_autopaged = 1'b1;
  reg divmmc_autopage_status_after_m1 = 1'b1;
  always @(negedge mreq_n or negedge rst_n) begin
    if (rst_n == 1'b0) begin
      divmmc_is_autopaged <= 1'b1;
      divmmc_autopage_status_after_m1 <= 1'b1;
    end
    else begin
      if (m1_n == 1'b0) begin
        if (a==16'h0000 || inrom48k && (a==16'h0008 || a==16'h0038 || a==16'h0066 || a==16'h04C6 || a==16'h0562 )) begin  // Deferred automapping (maps at the next CPU clock cycle)
          divmmc_autopage_status_after_m1 <= 1'b1;
        end
        else if (a[15:8]==8'h3D && inrom48k) begin  // Non deferred automapping (Current CPU clock cycle)
          divmmc_is_autopaged <= 1'b1;
          divmmc_autopage_status_after_m1 <= 1'b1;
        end
        else if (a[15:3]==13'b0001111111111) begin  // Deferred automapping deactivation
          divmmc_autopage_status_after_m1 <= 1'b0;
        end
      end
      else
        divmmc_is_autopaged <= divmmc_autopage_status_after_m1;      
    end
  end

  // Signal NMI only when DivMMC memory is not paged. This prevents signal bouncing
  assign nmi_to_cpu_n = (nmi_button_n == 1'b0 && divmmc_is_autopaged == 1'b0)? 1'b0 : 1'b1;
  
  // EEPROM, ROMCS and SRAM control and address lines
  always @* begin
    eeprom_cs = 1'b0;
    sram_cs = 1'b0;
    sram_hiaddr = {~divmmc_sram_page[5:4],divmmc_sram_page[3:0]};
    sram_write_n = 1'b1;
    eeprom_we_n = 1'b1;

    if (conmem == 1'b1 || divmmc_is_autopaged == 1'b1 && (enable_autopage == 1'b1 || mapram_mode == 1'b1))
      zxromcs = 1'b1;
    else
      zxromcs = 1'b0;
   
    if (mreq_n == 1'b0 && a[15:14] == 2'b00 /*&& (rd_n == 1'b0 || wr_n == 1'b0)*/ ) begin
   
    //So, when CONMEM is set, there is:
    //0000-1fffh - EEPROM/EPROM/NOTHING(if empty socket), and this area is
    //	   flash-writable if EPROM jumper is open.
    //2000-3fffh - 8k bank, selected by BANK 0..1 bits, always writable.
    if (conmem == 1'b1) begin
      if (a[13] == 1'b0) begin
        if (rd_n == 1'b0) 
          eeprom_cs = 1'b1;
        if (enable_autopage == 1'b0)
          eeprom_we_n = wr_n;
      end  
      else begin
        if (rd_n == 1'b0)
          sram_cs = 1'b1;
        sram_write_n = wr_n;
        sram_hiaddr = {~divmmc_sram_page[5:4],divmmc_sram_page[3:0]};
      end
    end
    
    //When MAPRAM is set, but CONMEM is zero, and entrypoint was reached:
    //0000-1fffh - Bank No.3, read-only
    //2000-3fffh - 8k bank, selected by BANK 0..1. If it's different from Bank No.3,
    //	   it's writable.
    else if (mapram_mode == 1'b1 && conmem == 1'b0 && divmmc_is_autopaged == 1'b1) begin
      if (a[13] == 1'b0) begin
        if (rd_n == 1'b0) begin
          sram_cs = 1'b1;
          sram_hiaddr = 6'b110011;
          sram_write_n = 1'b1;
        end
      end
      else begin
        if (rd_n == 1'b0)
          sram_cs = 1'b1;
        sram_hiaddr = {~divmmc_sram_page[5:4],divmmc_sram_page[3:0]};
        if (divmmc_sram_page != 6'd3) begin
          sram_write_n = wr_n;
        end
        else begin
          sram_write_n = 1'b1;
        end
      end
    end
   
    //When MAPRAM is zero, CONMEM is zero, EPROM jumper is closed and entrypoint was
    //reached:
    //0000-1fffh - EEPROM/EPROM/NOTHING(if empty socket, so open jumper in this case),
    //	   read-only.
    //2000-3fffh - 8k bank, selected by BANK 0..1, always writable.
    else if (enable_autopage == 1'b1 && mapram_mode == 1'b0 && conmem == 1'b0 && divmmc_is_autopaged == 1'b1) begin
      if (a[13] == 1'b0) begin
        if (rd_n == 1'b0)
          eeprom_cs = 1'b1;
      end
      else begin
        if (rd_n == 1'b0)
          sram_cs = 1'b1;
        sram_write_n = wr_n;
        sram_hiaddr = {~divmmc_sram_page[5:4],divmmc_sram_page[3:0]};
      end
    end
    
    //Otherwise, there's normal speccy memory layout. No modified ROM, no shit.  
    else begin
      eeprom_cs = 1'b0;
      sram_cs = 1'b0;
      sram_write_n = 1'b1;
    end
   
    end // del IF que nos dice si estamos accediendo a los primeros 16KB
  end // del always

  sd_card_control sd (
    .clk(clk),
    .rst_n(rst_n),
    .a(a[7:0]),
    .iorq_n(iorq_n),
    .rd_n(rd_n),
    .wr_n(wr_n),
    .din(din),
    .dout(dout),
    .oe(oe),

    .sd_cs0_n(sd_cs0_n),
    //.sd_cs1_n(sd_cs1_n),
    .sd_sclk(sd_sclk),
    .sd_mosi(sd_mosi),
    .sd_miso(sd_miso)
    );

endmodule
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

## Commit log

2024-10-19 Add schematics, IBOM, case STLs, kicad project
    [button-2-nmi.stl, button-2-reset.stl, button.scad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]
2024-12-19 Add top enclosure without JTAG and switch holes
    [enclosure_top_no_jtag_no_switch.stl]
2024-12-23 Cosmetic fix: change R1 footprint from C_0603 to R_0603 and update IBOM
    [divtiesus.kicad_pcb, divtiesus.kicad_sch]
2024-12-23 README: add a link to PCBWay project
2024-12-23 README: mention necessary files for enclosure
    Also rename out/case to out/enclosure
    [button-2-nmi.stl, button-2-reset.stl, button.scad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]
2025-09-24 Switch UART to Spectrum Next-like interface
2025-09-24 Revert "Switch UART to Spectrum Next-like interface"
    This reverts commit e17d2df9fd5a1b8940326b4a016df15eee8210e9.
    [tld_divtiesus.qsf]

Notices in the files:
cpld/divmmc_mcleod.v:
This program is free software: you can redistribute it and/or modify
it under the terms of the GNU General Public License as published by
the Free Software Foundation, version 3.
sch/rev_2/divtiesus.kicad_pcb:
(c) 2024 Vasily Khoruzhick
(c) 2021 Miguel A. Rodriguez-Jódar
